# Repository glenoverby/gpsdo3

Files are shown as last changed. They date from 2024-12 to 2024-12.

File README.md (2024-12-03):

# gpsdo3
Improved GPS Disciplined Oscillator

This is a GPS Disciplined Oscillator for synchronizing a 10MHz osillator
with the timing signal from GPS.

This project include a printed circuit board (designed in KiCad) and software
(using Arduino).  It runs on a SparkFun SAMD21 Mini Breakout.

A full description of the project is in the 'doc' directory.

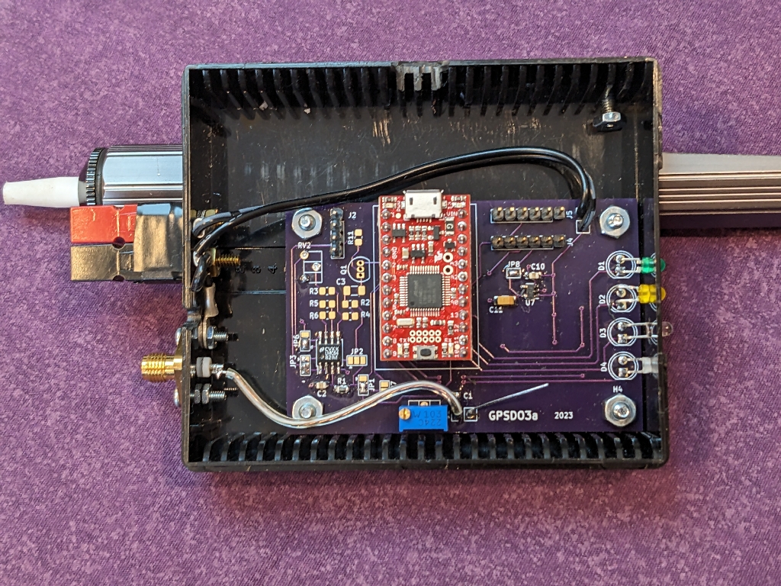
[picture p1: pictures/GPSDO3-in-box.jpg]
Image of board wired up


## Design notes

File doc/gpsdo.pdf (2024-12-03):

# An Improved GPS Disciplined Oscillator

Glen Overby, KC0IYT 11/2024 This is a GPS Disciplined Oscillator for synchronizing a 10MHz signal source with the timing signal from GPS. It uses a Atmel/Microchip SAMD-21 microcontroller to achieve this.

## Background

This is a follow-on to my 2017 GPSDO project with an improved PCB and improved software. The software now locks a 10MHz oscillator such that when driving a synthesized oscillator at 5.7GHZ, the signal will be within 500HZ and locks up in less than 30 seconds from when the GPS gets a 3D lock and produces an accurate 1PPS signal.
My 2017 GPSDO project never worked well for me, primarily because the lock time was too long. I purchased a GPSDO made by a Chinese ham, BG7TBL, and was using it on my 10GHz ham radio station in the summer of 2023. I had a number of comments about the amount of spurious garbage on my RF signal at 10GHz, which resulted in my doing comparisons of driving a 10GHz synthesized oscillator with several different oscillators: the GPSDO, and several good quality ovenised oscillators (OCXOs). The difference was easily apparent: the OCXOs were much better. Even my own GPSDO turned the output from a good OCXO into one that generated spurs. I needed something better.
There are other commercial GPSDOs available, probably for less than I spent on this project, but I heard some bad signals on the radio from people who were using them. I decided to make improvements to my own GPSDO (in retrospect, this may have been due to their power supply).

## Hardware

My Version 1 GPSDO project used a TI MSP432 microcontroller. There were some compromises, like not being able to read the GPS serial stream directly, due to pins being shared between the microcontroller’s peripherals. The development environment, based on Eclipse, ran on Windows and I prefer to use Linux. So for a GPSDO revision, a change in microcontroller was on the table. I had purchased some SparkFun SAMD21 based Arduino boards, which use a 30 MHz ARM chip with a large set of peripherals, for a model rocket project. It’s completely overkill for the task at hand. However, the MegaAVRs weren’t quite up to the task of counting a 10 MHz clock. The SparkFun SAMD-21 Arduio board costs about $20, and I might make 2 or 3 of them, my time is a bigger factor than the cost of the chip.
I prototyped a new GPSDO using an unused GPSDO v1 PCB with good results, so I proceeded

1

with the project.
One of the lessons I learned with the version 1 was to have separate voltage regulators for different parts of the circuit. In particular, the GPS needs to not share a regulator with the microcontroller. My V1 GPSDO had a 1HZ noise pulse that was remedied by moving the GPS module to it’s own regulator.
Another lesson in power domains was turning on/off LEDs affected the PWM output voltage enough to cause a noticeable sawtooth pattern on the output signal at 10GHz. This problem did not repeat during this project, even though the LEDs are driven by the microcontroller. This may be due, in part, to using the microcontroller to sink current (the ground side of LEDs is connected to the chip) instead of source it. The one exception to this is the red/green LED for the GPS lock.
Another discovery I made while working with the prototype - that might explain problems with v1 - was how much better the resulting oscillator’s signal was when driven from the SAMD21’s DAC as compared to a PWM signal with filters. The MSP430 only had a PWM, while the SAMD21 has a real DAC (I assume it’s based on resistors). Even though the SAMD21 had a DAC on it, I started out using a PWM DAC because I believed I needed more than 10 bits of resolution to control the OCXO. That’s only partly correct; the number of bits required depends greatly on what OCXO is being used. The PCB has a footprint for a MCP 4725 12-bit DAC chip, in case I ever need a DAC with more resolution.
The Arduino environment supports using the SAMD-21 USB hardware as a client, making it look like a serial port to the host. This means I only had to use one hardware serial port to listen to the GPS for lock signal (the SAMD-21 has multiple hardware serial ports).
Inputs from the oscillator, GPS, etc. are buffered using a 74HCT125 chip. The HCT technology is safe to use with +5V inputs when the chip is powered by 3.3v.
The serial port connections use a 6-pin header compatible with the headers used on many Arduino boards and many USB to Serial adapters. There is one header to connect to the GPS receiver (with the 1PPS signal taking over the DTR pin). A second header is present to connect a USB-to-Serial adapter to the GPS receiver.
A header is provided for connections to the oscillator. It includes power for the voltage control op-amp and a signal for when the oscillator has reached operating temperature (both of those were inspired by the Isotemp OCXOs).
There are many jumper points on the board:
JP1 selects the CPU DAC or PWM pins. JP7 connects the output pin of the external DAC, if used (KiCad doesn’t have a 3-way jumper). This signal goes to an RC filter then to the first half of op-amp U1.
JP2 selects the input of the second half of op-amp U1. Options are the output of the first half of U1 or the signal selected by JP1/JP7.
JP3 selects which op-amp section goes to the OCXO control.

2

JP5 selects where the op-amp power comes from: either the 3.3v rail or the Oscillator’s control voltage.
JP4, JP5 and JP8 are on the outputs of the voltage regulators. This allows testing the voltage regulator without powering any circuitry, and measuring current draw.
The first half of op-amp U1 is a simple input follower[2] after filter R1/C2. The second half has component footprints (R3, R4, R5, R6, RV2) to make it a summing amplifier[1]. This was intended to provide an offset voltage for use with OCXOs that require a control voltage higher than 3.3v. Alternatively, it can be a non-inverting amplifier[1] with a gain greater than 1 by placing resistors at R5, R6.
The 10MHz clock source is terminated by RV1, a 5K ohm variable resistor. This resistor is used to adjust the voltage level seen by the 74HCT125 input, and is the only tuning the board requires. Adjust the resistor so the 10MHz signal appears on the output of U2, pin 8. I needed an oscilloscope to get this setting right.

## Software

I had many ideas for how to improve the GPS lock software. The software is a PID controller (PID controllers are described in detail in various places on the the internet; I won’t try to go into them here). The major problem I needed to address was the time it takes to lock the oscillator frequency to the GPS timing signal.
My V1 software always averaged multiple 1PPS clocks before operating on them. This was to remove jitter in the GPS signal (or maybe in the receiver chip). The jitter usually exhibited itself as one clock that was long or short, with the next clock compensating.
I decided that the P controller, which is doing only a rough lock to 1PPS, can operate well even with a little bit of jitter from the GPS since the P controller has a small error band. This version does that, and by operating every second, it locks the oscillator much faster than the old version. For the I controller, I continue to average several 1PPS clocks but do so using a moving average. This allows running the I controller every second. I discovered that I needed to use double precision floating point to have enough bits for an average of 10,000,000 samples and including a fraction (single precision, 32 bits, used all the bits for the integer portion of the number). It’s good that I picked a microcontroller that was a lot of overkill! I’ve since revisited this decision and am now tracking the error (how far from 10,000,000 the actual count is) and single precision floating point works well.
The software starts as a P controller then switches to an I controller once P is stable “enough”. It will switch back to the P controller if an adjustment needs to be too large.
I found that after making adjustments in the I controller, I really needed to flush out the accumulated error. If I didn’t, the I controller would swing from too fast to too slow, never (or rarely) stopping in the middle.
Configuring the SAMD21 is quite complicated. I borrowed code from the Arduino forum for

3

configuring a counter with an external clock and a capture-and-hold. The choice in what counter and sample and hold determined what pins the 10MHz signal and the PPS signal were connected. Similarly, the code for initializing the PWM DAC was borrowed from the Arduino wiring_analog library (which I actually call once during configuration so that I didn’t need to duplicate even more code).
Once the board has been assembled an the OCXO connected,
I’ve used this to control several OCXOs:
- CTi OSC5A2B02
- Isotemp 134-10
- FOX 801

## Lessons Learned

There were a few problems encountered along the way:
I configured A0, shared with the DAC output, as a digital output. This caused a problem where the DAC wouldn’t swing all the way to 3.3v due to the digital signal pulling it down. I left the initialization in the code, commented out, along with a warning to my future self not to use it. Whenever the counter for the 10MHz clock wraps at 2**32, it reports 32 extra clocks. I don’t know where it gets them. It’s not good to interject a glitch every 429 seconds, so I check for outliers and throw away bad samples. Just in case something goes awry, there is a counter: if 10 outliers in a row happen, the code kicks back to the P controller (that actually happened when a test clip came off).
While the PI controllers need to operate based on the 1PPS GPS clock, I needed status LEDs to update even when that clock isn’t present (e.g. to update the GPS lock LED to RED!). The loop() function uses the Arduino millis() call to get the time, and updates LEDs about every 2 seconds. The heartbeat update will be noticeably slower when this is happening.
The normal program output, on the USB serial port, only shows status when changes are made to the OCXO control signal. Debugging can be turned on to increase the amount of chatter. All messages from the GPS can be echoed to that serial port as well. Normally only the $GPRMC signal is passed (which can be used to set a computer’s clock).
The second board I built didn’t include the 10K trim pot on the I found that oscillators weren’t behaving themselves. After adding it, things improved significantly. I think the oscillators didn’t like the high impedance input and need the ~5k ohms of termination.
I’m using a resistive power splitter on the oscillator output, but I think I need to add a MMIC on each side of the splitter both for isolation and to bring the power level up. I have several of the CTi oscillators, and the ones without the GPSDO are cleaner than the ones on the GPSDO.
The FOX 801 really needs more than a 10 bit DAC. I used those with my V1 GPSDO which is

4

probably why I started this project thinking that I couldn’t use the 10-bit DAC.
I’ve found that having a GPS with a separate antenna is a lot more useful than having the antenna integrated with the GPSDO box. With an external antenna, I can mount the GPSDO wherever it works best, without requiring that the whole thing having a sky view.
While I’ve put the GPSDO in a plastic box, I’ve been keeping the oscillator in a separate metal box.

## Future

Some things that could use improving for future versions:
I have a simple RC filter on the control output, along with op-amps to buffer it. I should try using a salen-key low pass filter with one of the op-amps.
I designed the op-amp circuit to allow adding a constant voltage (Isotemp OCXOs use about 8v for the voltage control), but when I tried using that OCXO I actually used a 2x amplification. Provide some tap points for DC power and ground on the PCB – probably a 2nd 2-pin header right next to the first one. This would have made it easier to build a version that is integrated with the OCXO.
The header for the OCXO should be expanded to include a pin for power TO the OCXO, and a jumper to connect it to +12v power coming onto the board.
Label the GPS connectors better. There are two 6-pin headers (compatible with readily available USB to serial boards used on Arduinos): one connects to the GPS, another to a USB-to-Serial adapter in case I ever wish to program the GPS. It’s easy to forget which is which, and which way to connect the cable.
There may be better ways to buffer the input 10MHz signal. A similar project by VE2ZAZ published in QEX[3] used an LTC1485 differential bus transceiver.

## References

[1] National Semiconductor AN-31 “Op Amp Circuit Collection”, February 1978. Non-Inverting Summing Amplifier
[2] National Semiconductor LMC6482 “CMOS Dual Rail-To-Rail Input and Output Operational Amplifier” data sheet, November 1977, Figure 10.
[3] “A Simplified GPS-Derived Frequency Standard”, Bertrand Zauhar VE2ZAZ QEX Sep 2006 pp 14 https://webpubs.arrl.org/pubs_archive/113782

5

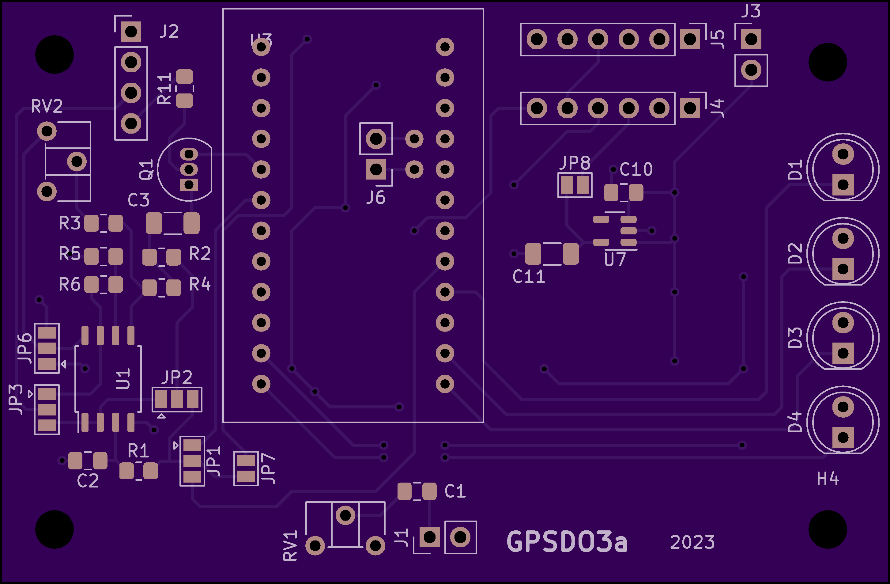
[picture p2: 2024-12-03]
pictures/GPSDO3-top.png

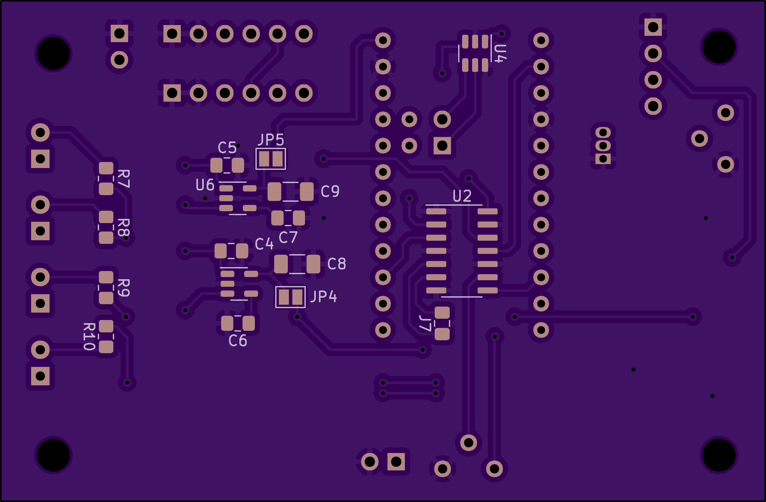
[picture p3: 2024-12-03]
pictures/GPSDO3-bottom.png

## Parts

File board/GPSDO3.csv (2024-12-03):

Source: | /home/glen/kicad/GPSDO3/GPSDO3.kicad_sch
Date: | Tue Nov 14 01:06:51 2023
Tool: | Eeschema 7.0.9-7.0.9~ubuntu22.04.1
Generator: | /usr/share/kicad/plugins/bom_csv_grouped_by_value.py
Component Count: | 55
Collated Components:
Item | Qty | Reference(s) | Value | LibPart | Footprint | Datasheet | DNP
1 | 1 | C1 | C | Device:C | Capacitor_SMD:C_0805_2012Metric_Pad1.18x1.45mm_HandSolder | ~
2 | 4 | C2, C4, C5, C10 | 1uF | Device:C | Capacitor_SMD:C_0805_2012Metric_Pad1.18x1.45mm_HandSolder | ~
3 | 1 | C3 | 1uF | Device:C | Capacitor_SMD:C_1206_3216Metric_Pad1.33x1.80mm_HandSolder | ~
4 | 2 | C6, C7 | 470pF | Device:C | Capacitor_SMD:C_0805_2012Metric_Pad1.18x1.45mm_HandSolder | ~
5 | 3 | C8, C9, C11 | 2.2uF | Device:C_Polarized_US | Capacitor_SMD:C_1206_3216Metric_Pad1.33x1.80mm_HandSolder | ~
6 | 4 | D1, D2, D3, D4 | LED | Device:LED | LED_THT:LED_D5.0mm | ~
7 | 4 | H1, H2, H3, H4 | MountingHole | Mechanical:MountingHole | MountingHole:MountingHole_3.2mm_M3 | ~
8 | 1 | J1 | Conn_Coaxial | Connector:Conn_Coaxial | Connector_PinHeader_2.54mm:PinHeader_1x02_P2.54mm_Vertical | ~
9 | 1 | J2 | To OSC | Connector:Conn_01x04_Male | Connector_PinHeader_2.54mm:PinHeader_1x04_P2.54mm_Vertical | ~
10 | 1 | J3 | Power | Connector:Conn_01x02_Male | Connector_PinHeader_2.54mm:PinHeader_1x02_P2.54mm_Vertical | ~
11 | 1 | J4 | To GPS | Connector:Conn_01x06_Male | Connector_PinHeader_2.54mm:PinHeader_1x06_P2.54mm_Vertical | ~
12 | 1 | J5 | To Computer | Connector:Conn_01x06_Male | Connector_PinHeader_2.54mm:PinHeader_1x06_P2.54mm_Vertical | ~
13 | 1 | J6 | Conn_01x02_Male | Connector:Conn_01x02_Male | Connector_PinHeader_2.54mm:PinHeader_1x02_P2.54mm_Vertical | ~
14 | 1 | J7 | Conn_01x02_Male | Connector:Conn_01x02_Male | Capacitor_SMD:C_0805_2012Metric_Pad1.18x1.45mm_HandSolder | ~
15 | 1 | JP1 | CPU PWM - DAC | Jumper:SolderJumper_3_Bridged12 | Jumper:SolderJumper-3_P1.3mm_Open_Pad1.0x1.5mm | ~
16 | 1 | JP2 | Gate2 Input | Jumper:SolderJumper_3_Bridged12 | Jumper:SolderJumper-3_P1.3mm_Open_Pad1.0x1.5mm | ~
17 | 1 | JP3 | OSC Vcontrol | Jumper:SolderJumper_3_Bridged12 | Jumper:SolderJumper-3_P1.3mm_Open_Pad1.0x1.5mm | ~
18 | 1 | JP4 | 5V #1 Jumper | Jumper:SolderJumper_2_Open | Jumper:SolderJumper-2_P1.3mm_Open_Pad1.0x1.5mm | ~
19 | 1 | JP5 | 5V #2 Jumper | Jumper:SolderJumper_2_Open | Jumper:SolderJumper-2_P1.3mm_Open_Pad1.0x1.5mm | ~
20 | 1 | JP6 | ~ | Jumper:SolderJumper_3_Bridged12 | Jumper:SolderJumper-3_P1.3mm_Open_Pad1.0x1.5mm | ~
21 | 1 | JP7 | SolderJumper_2_Open | Jumper:SolderJumper_2_Open | Jumper:SolderJumper-2_P1.3mm_Open_Pad1.0x1.5mm | ~
22 | 1 | JP8 | 3.3V Jumper | Jumper:SolderJumper_2_Open | Jumper:SolderJumper-2_P1.3mm_Open_Pad1.0x1.5mm | ~
23 | 1 | Q1 | 2N3904 | Transistor_BJT:2N3904 | Package_TO_SOT_THT:TO-92_Inline | https://www.onsemi.com/pub/Collateral/2N3903-D.PDF
24 | 4 | R1, R2, R3, R4 | 100K | Device:R_US | Resistor_SMD:R_0805_2012Metric_Pad1.20x1.40mm_HandSolder | ~
25 | 2 | R5, R6 | 10K | Device:R_US | Resistor_SMD:R_0805_2012Metric_Pad1.20x1.40mm_HandSolder | ~
26 | 5 | R7, R8, R9, R10, R11 | R_US | Device:R_US | Resistor_SMD:R_0805_2012Metric_Pad1.20x1.40mm_HandSolder | ~
27 | 1 | RV1 | R_Potentiometer_US | Device:R_Potentiometer_US | Potentiometer_THT:Potentiometer_ACP_CA6-H2,5_Horizontal | ~
28 | 1 | RV2 | 10K | Device:R_Potentiometer_US | Potentiometer_THT:Potentiometer_ACP_CA6-H2,5_Horizontal | ~
29 | 1 | U1 | LMC6482 | Amplifier_Operational:LMC6482 | Package_SO:SOIC-8_5.23x5.23mm_P1.27mm | http://www.ti.com/lit/ds/symlink/lmc6482.pdf
30 | 1 | U2 | 74LVC125 | 74xx:74LVC125 | Package_SO:SOIC-14_3.9x8.7mm_P1.27mm | http://www.ti.com/lit/gpn/sn74LVC125
31 | 1 | U3 | SFE_SAMD21_Mini | Glen_Arduino:SFE_SAMD21_Mini | Glen_Arduino:SFE SAMD21 Mini
32 | 1 | U4 | MCP4725xxx-xCH | Analog_DAC:MCP4725xxx-xCH | Package_TO_SOT_SMD:SOT-23-6 | http://ww1.microchip.com/downloads/en/DeviceDoc/22039d.pdf
33 | 1 | U5 | MIC5205-3.3YM5 | Regulator_Linear:MIC5205-3.3YM5 | Package_TO_SOT_SMD:SOT-23-5 | http://ww1.microchip.com/downloads/en/DeviceDoc/20005785A.pdf
34 | 2 | U6, U7 | MIC5205-5.0YM5 | Regulator_Linear:MIC5205-5.0YM5 | Package_TO_SOT_SMD:SOT-23-5 | http://ww1.microchip.com/downloads/en/DeviceDoc/20005785A.pdf

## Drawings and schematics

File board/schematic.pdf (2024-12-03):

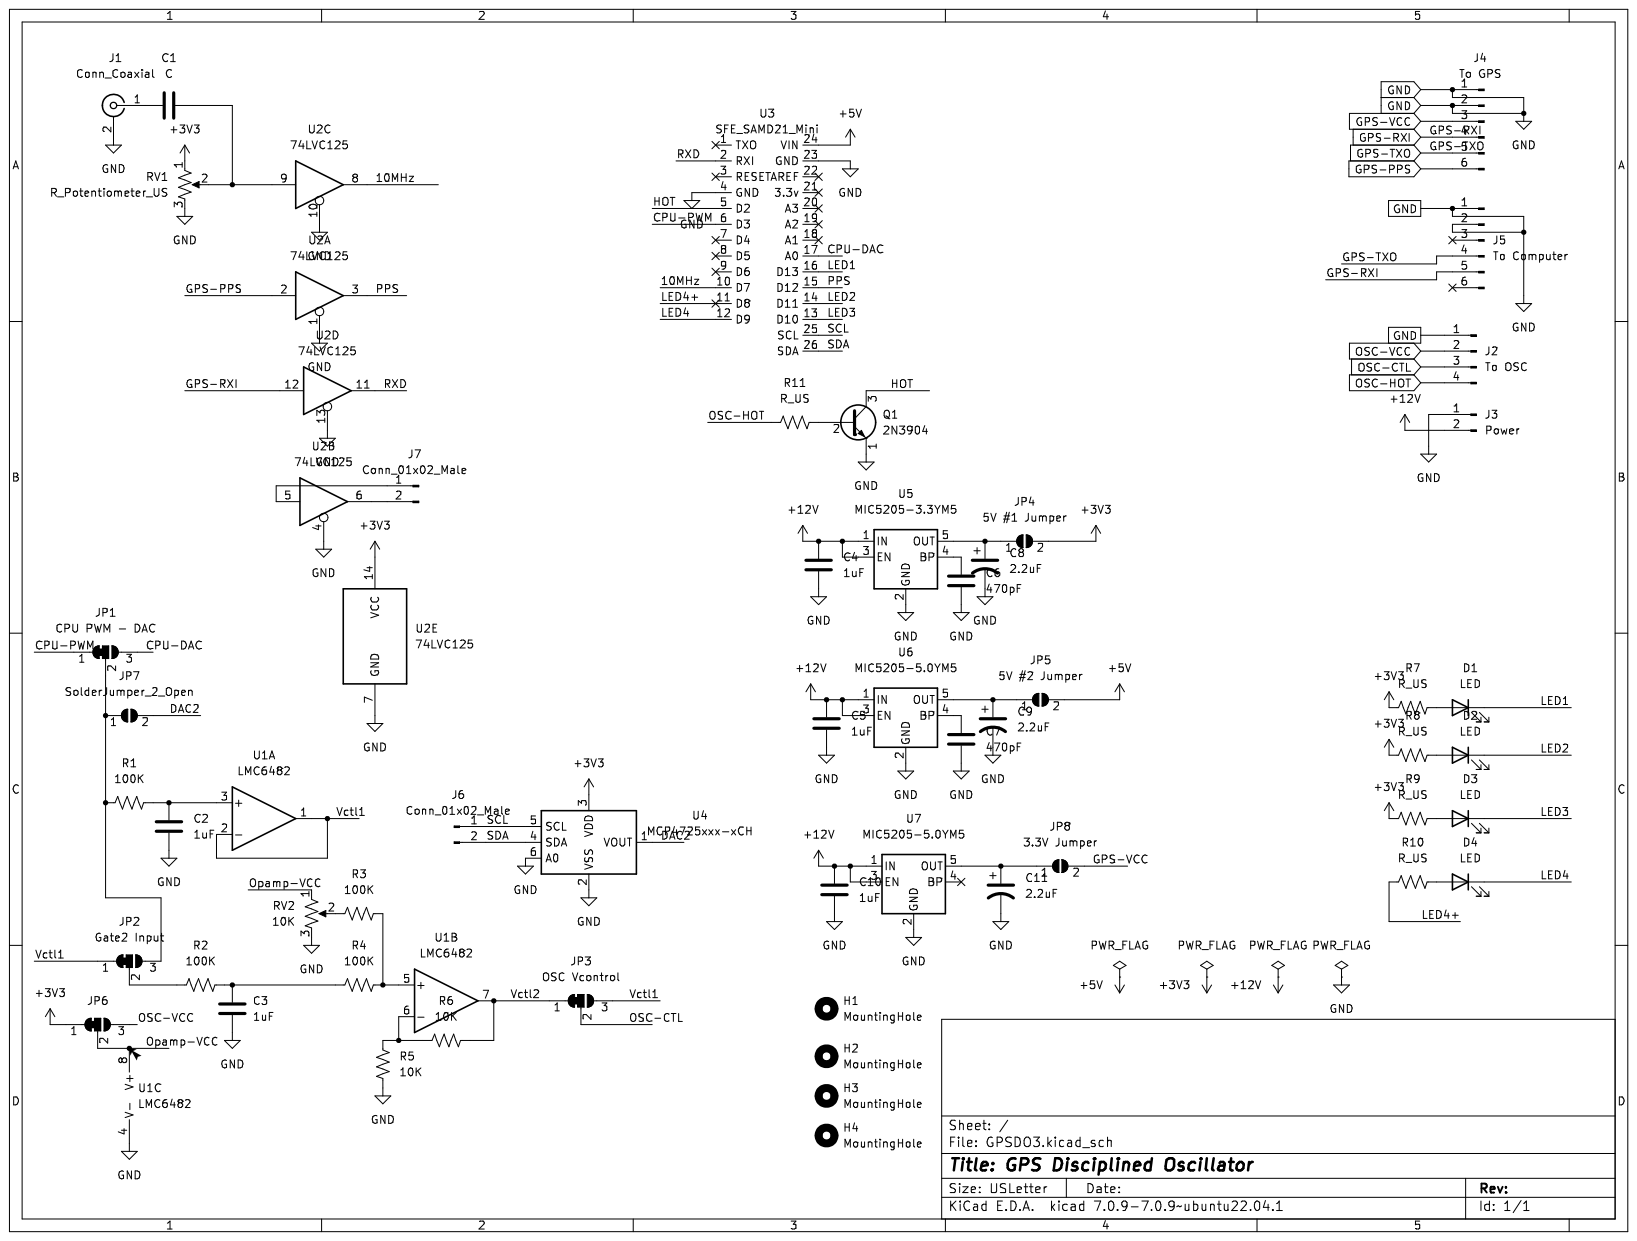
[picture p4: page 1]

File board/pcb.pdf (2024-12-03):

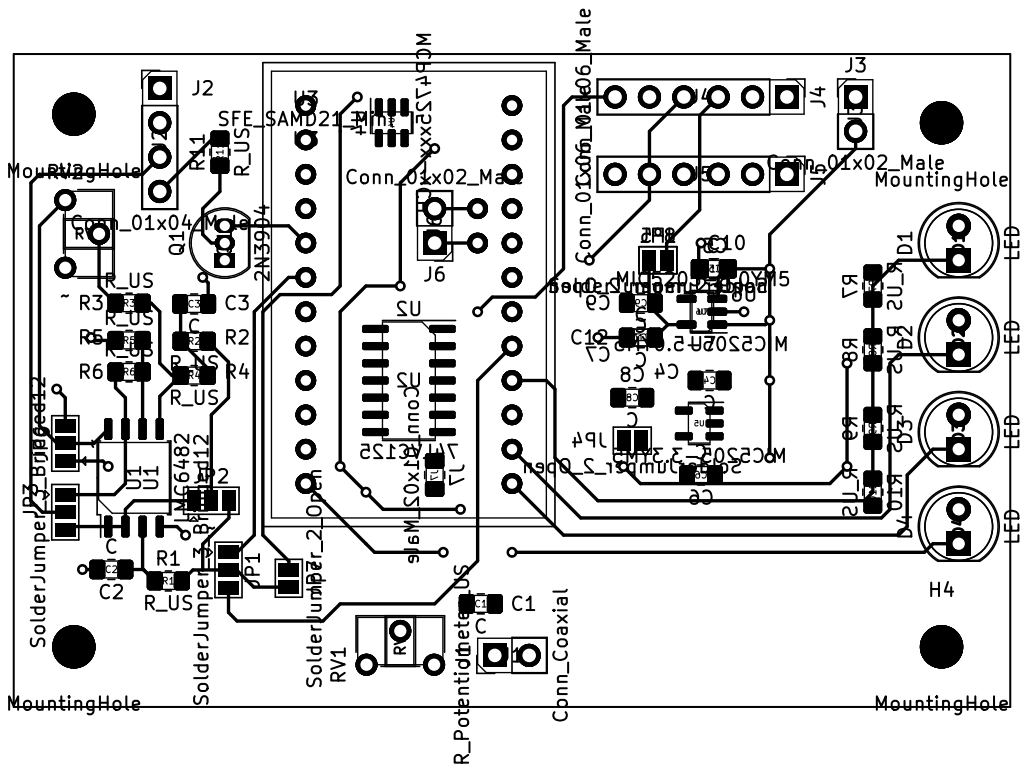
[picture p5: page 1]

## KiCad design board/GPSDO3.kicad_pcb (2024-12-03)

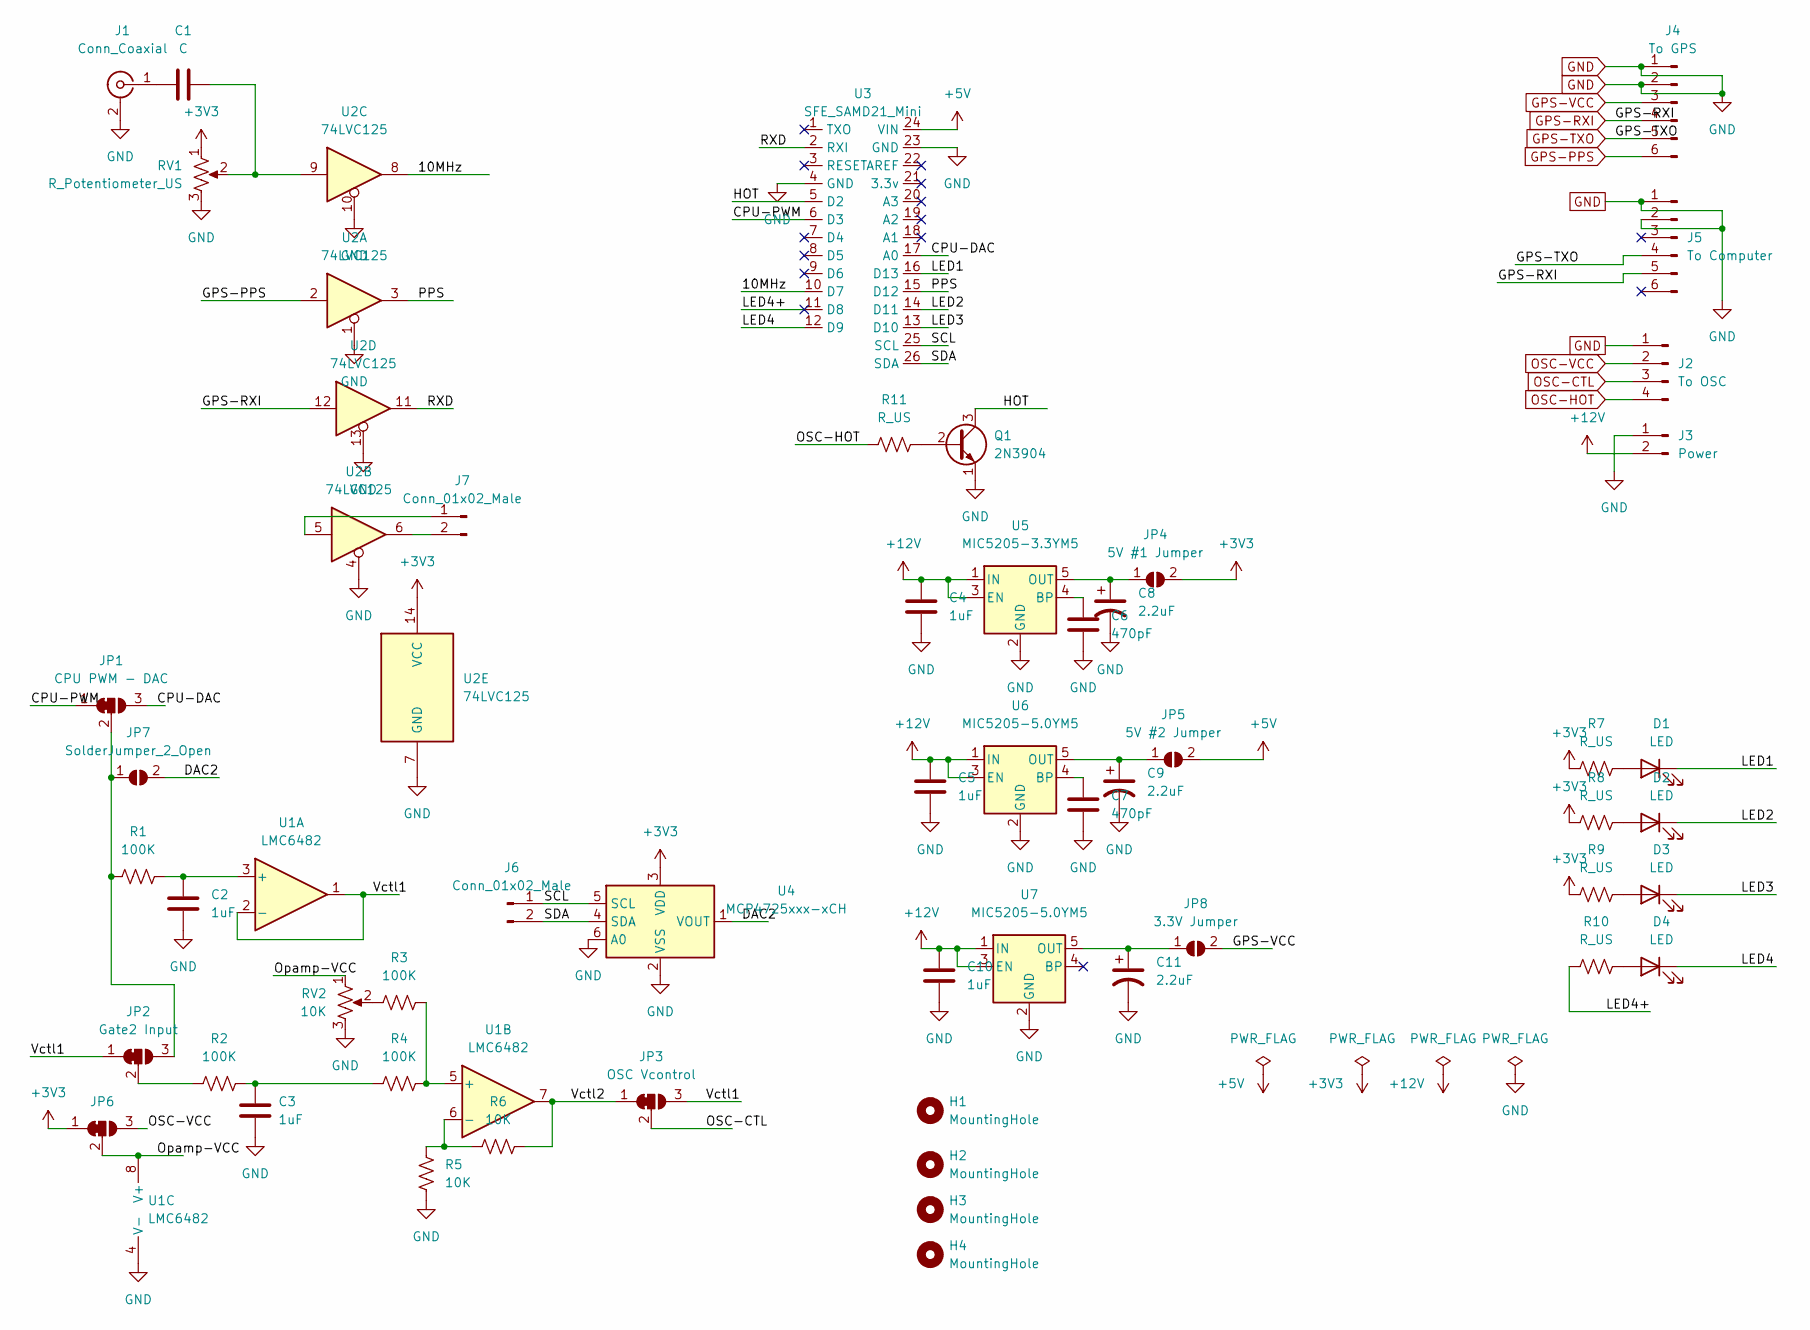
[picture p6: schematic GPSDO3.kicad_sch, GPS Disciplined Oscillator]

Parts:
C1: C; C_0805_2012Metric_Pad1.18x1.45mm_HandSolder
C2, C4, C5, C10: 1uF; C_0805_2012Metric_Pad1.18x1.45mm_HandSolder
C3: 1uF; C_1206_3216Metric_Pad1.33x1.80mm_HandSolder
C6, C7: 470pF; C_0805_2012Metric_Pad1.18x1.45mm_HandSolder
C8, C9, C11: 2.2uF; C_1206_3216Metric_Pad1.33x1.80mm_HandSolder
D1, D2, D3, D4: LED; LED_D5.0mm
H1, H2, H3, H4: MountingHole; MountingHole_3.2mm_M3
J1: Conn_Coaxial; PinHeader_1x02_P2.54mm_Vertical
J2: To OSC; PinHeader_1x04_P2.54mm_Vertical
J3: Power; PinHeader_1x02_P2.54mm_Vertical
J4: To GPS; PinHeader_1x06_P2.54mm_Vertical
J5: To Computer; PinHeader_1x06_P2.54mm_Vertical
J6: Conn_01x02_Male; PinHeader_1x02_P2.54mm_Vertical
J7: Conn_01x02_Male; C_0805_2012Metric_Pad1.18x1.45mm_HandSolder
JP1: CPU PWM - DAC; SolderJumper-3_P1.3mm_Open_Pad1.0x1.5mm
JP2: Gate2 Input; SolderJumper-3_P1.3mm_Open_Pad1.0x1.5mm
JP3: OSC Vcontrol; SolderJumper-3_P1.3mm_Open_Pad1.0x1.5mm
JP4: 5V #1 Jumper; SolderJumper-2_P1.3mm_Open_Pad1.0x1.5mm
JP5: 5V #2 Jumper; SolderJumper-2_P1.3mm_Open_Pad1.0x1.5mm
JP6: SolderJumper-3_P1.3mm_Open_Pad1.0x1.5mm
JP7: SolderJumper_2_Open; SolderJumper-2_P1.3mm_Open_Pad1.0x1.5mm
JP8: 3.3V Jumper; SolderJumper-2_P1.3mm_Open_Pad1.0x1.5mm
Q1: 2N3904; TO-92_Inline
R1, R2, R3, R4: 100K; R_0805_2012Metric_Pad1.20x1.40mm_HandSolder
R5, R6: 10K; R_0805_2012Metric_Pad1.20x1.40mm_HandSolder
R7, R8, R9, R10, R11: R_US; R_0805_2012Metric_Pad1.20x1.40mm_HandSolder
RV1: R_Potentiometer_US; Potentiometer_ACP_CA6-H2,5_Horizontal
RV2: 10K; Potentiometer_ACP_CA6-H2,5_Horizontal
U1: LMC6482; SOIC-8_5.23x5.23mm_P1.27mm
U2: 74LVC125; SOIC-14_3.9x8.7mm_P1.27mm
U3: SFE_SAMD21_Mini; SFE SAMD21 Mini
U4: MCP4725xxx-xCH; SOT-23-6
U5: MIC5205-3.3YM5; SOT-23-5
U6, U7: MIC5205-5.0YM5; SOT-23-5

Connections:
+3V3: JP4.2 (B), JP6.1 (A), R7.2, R8.2, R9.2, RV1.1, U2.14 (VCC), U4.3 (VDD)
+5V: JP5.2 (B), U3.24 (VIN)
+12V: C4.1, C5.1, C10.1, J3.2, U5.1 (IN), U5.3 (EN), U6.1 (IN), U6.3 (EN), U7.1 (IN), U7.3 (EN)
/10MHz: U2.8, U3.10 (D7)
/CPU-DAC: JP1.3 (B), U3.17 (A0)
/CPU-PWM: JP1.1 (A), U3.6 (D3)
/DAC2: JP7.2 (B), U4.1 (VOUT)
/HOT: Q1.3 (C), U3.5 (D2)
/LED1: D1.1 (K), U3.16 (D13)
/LED2: D2.1 (K), U3.14 (D11)
/LED3: D3.1 (K), U3.13 (D10)
/LED4: D4.1 (K), U3.12 (D9)
/LED4+: R10.2, U3.11 (D8)
/Opamp-VCC: JP6.2 (C), RV2.1, U1.8 (V+)
/PPS: U2.3, U3.15 (D12)
/RXD: U2.11, U3.2 (RXI)
/SCL: J6.1, U3.25 (SCL), U4.5 (SCL)
/SDA: J6.2, U3.26 (SDA), U4.4 (SDA)
/Vctl1: JP2.1 (A), JP3.3 (B), U1.1, U1.2 (-)
/Vctl2: JP3.1 (A), R6.2, U1.7
GND: C2.2, C3.2, C4.2, C5.2, C6.2, C7.2, C8.2, C9.2, C10.2, C11.2, J1.2 (Ext), J2.1, J3.1, J4.1, J4.2, J5.1, J5.2, Q1.1 (E), R5.2, RV1.3, RV2.3, U1.4 (V-), U2.1, U2.4, U2.7 (GND), U2.10, U2.13, U3.4 (GND), U3.23 (GND), U4.2 (VSS), U4.6 (A0), U5.2 (GND), U6.2 (GND), U7.2 (GND)
GPS-PPS: J4.6, U2.2
GPS-RXI: J4.4, J5.5, U2.12
GPS-TXO: J4.5, J5.4
GPS-VCC: J4.3, JP8.2 (B)
unnamed: C1.1, RV1.2, U2.9
unnamed: C3.1, R2.1, R4.2
unnamed: D1.2 (A), R7.1
unnamed: D2.2 (A), R8.1
unnamed: D3.2 (A), R9.1
unnamed: D4.2 (A), R10.1
unnamed: C1.2, J1.1 (In)
unnamed: J7.1, U2.5
unnamed: J7.2, U2.6
unnamed: JP1.2 (C), JP2.3 (B), JP7.1 (A), R1.2
unnamed: JP2.2 (C), R2.2
unnamed: C8.1, JP4.1 (A), U5.5 (OUT)
unnamed: C9.1, JP5.1 (A), U6.5 (OUT)
unnamed: C11.1, JP8.1 (A), U7.5 (OUT)
unnamed: Q1.2 (B), R11.1
unnamed: R3.2, RV2.2
unnamed: C2.1, R1.1, U1.3 (+)
unnamed: R3.1, R4.1, U1.5 (+)
unnamed: R5.1, R6.1, U1.6 (-)
unnamed: C6.1, U5.4 (BP)
unnamed: C7.1, U6.4 (BP)
OSC-CTL: J2.3, JP3.2 (C)
OSC-HOT: J2.4, R11.2
OSC-VCC: J2.2, JP6.3 (B)

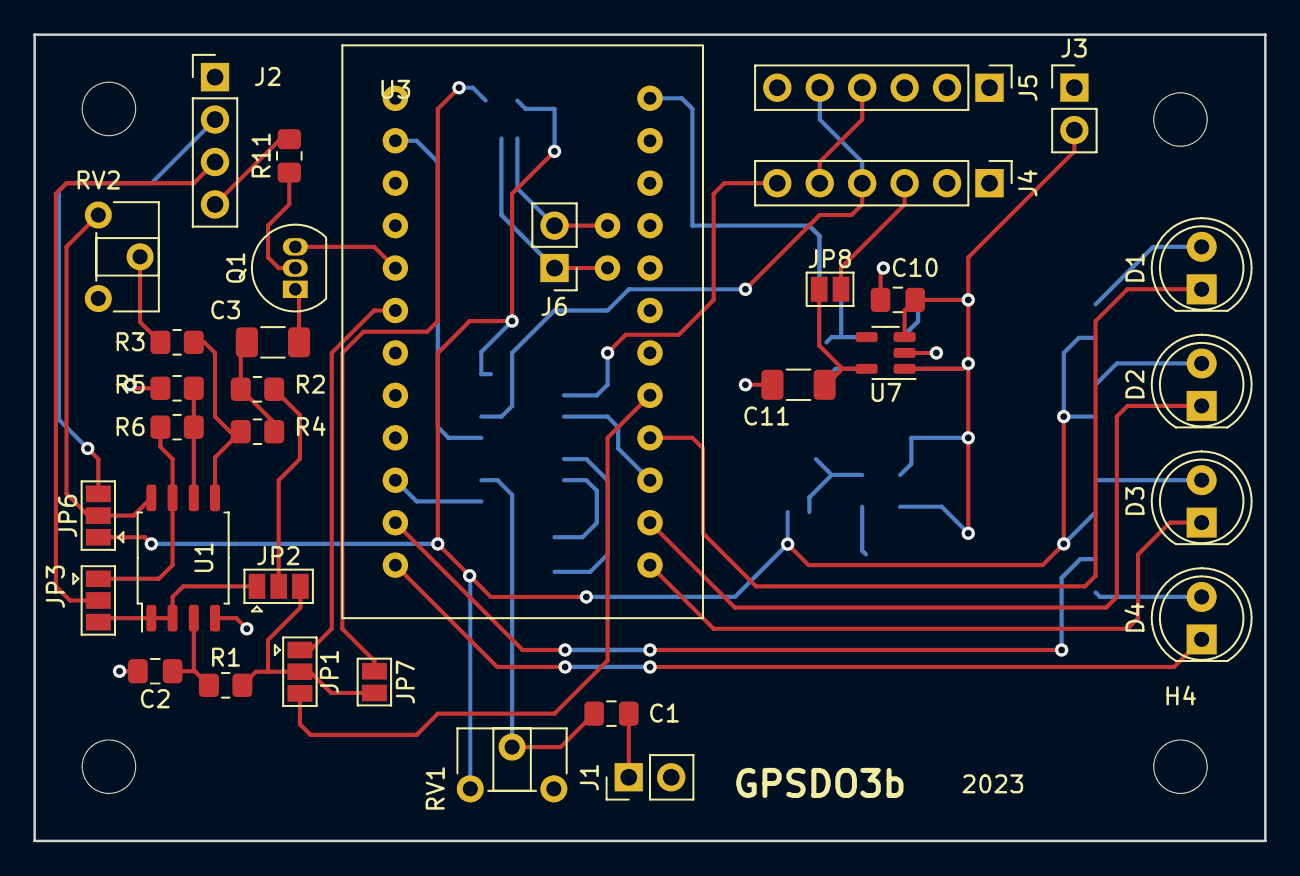
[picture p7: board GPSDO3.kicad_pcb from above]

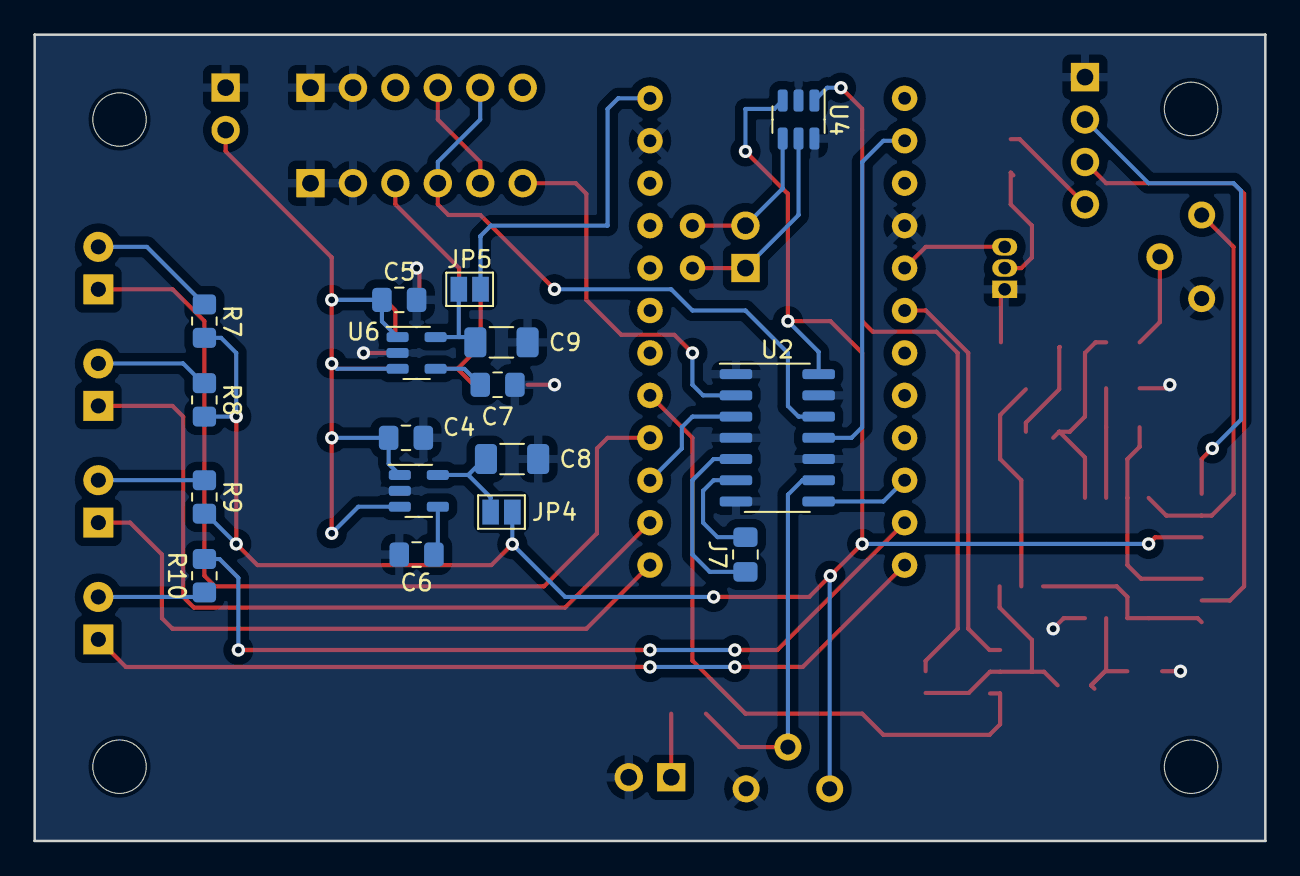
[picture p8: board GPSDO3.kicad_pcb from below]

Board: 2 copper layers, 73.7 x 48.3 mm, 55 parts (17 on the bottom side), 49 nets.

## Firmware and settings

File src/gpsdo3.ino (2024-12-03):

/*
 * Control Systemm for a GPS Disciplined Oscillator
 *
 * Copyright 2023-2024 Glen Overby
 * 
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
 */

// Arduino Pin  Processor Port  Function
// D13          PA17            Blue LED
// D12          PA19            1PPS from GPS
// D7           PA21            10MHz from oscillator
// D3           PA09            PWM output for VControl
//
// D2           PA14            Status LED - on when stable
// D5           PA15            Power LED - on when thinking
//
// D7 is difficult to move because TC4's input is on that pin
//
// LEDs:
//  D1  green     Lock
//  D2  red       Ready
//  D3  orange    Heartbeat
//  D4  red/green GPS status: red no lock, green lock, off no data


// Oscillator Configuration
// P_ADJUST  P controller adjustment factor for PWM DAC (not used)
// PD_ADJUST P controller adjustment factor for DAC
// If_ADJUST I controller adjustment factor
// PD_INIT   Initialization value for DAC
//            These values came from running the GPSDO during development
// USE_HOT  Use the OSC HOT input

#define CTI

#ifdef CTI  // CTi OS5SC25  square wave output oscillator
#define P_ADJUST  266
#define PD_ADJUST 10
#define If_ADJUST 16 / 100
#define PD_INIT -37	// SN#2
// #define ON_STABLE	// SN#1 has a green LED; SN#2 has a red LED
#endif
#ifdef OCXO13410  // Isotemp OCXO134-10
#define P_ADJUST  266
#define PD_ADJUST 25
#define If_ADJUST 24
#define PD_INIT 0
#define USE_HOT
#endif
#ifdef IQD2202   // IQD IQXT-220-2
#define P_ADJUST  266
#define PD_ADJUST 25
#define If_ADJUST 24
#define PD_INIT 0
#endif
#ifdef FOX801   // FOX 801
#define P_ADJUST  2
#define PD_ADJUST 3
#define If_ADJUST 1
#define PD_INIT  19      // initial value for P
#endif
#ifdef CW_T604   // Connor Williams (never got it fully working)
#define P_ADJUST  2
#define PD_ADJUST 1
#define If_ADJUST 1
#define PD_INIT  0      // initial value for P
#endif

#define HEARTBEAT_LED 10   // changes every second to make me happy.
                          // Shows that 1PPS is coming from GPS
#define GPS_LED_A   8     // Red/Green LED. Off=no data, R=no lock, G=2d/3d lock
#define GPS_LED_B   9
#define LOCK_LED   13   // oscillator is locked. Also blue LED
#define READY_LED  11   // general ready.
                        // Oscillator HOT signal would contribute to this.

#define HOT_PIN   2     // Oscillator HOT input (use pull-up)


uint32_t last_count, current_count;
volatile int flag = 0;
uint dacv = 0; // Hardware DAC (10 bits)
int settle=3, Isettle=0;  // Settle timer for startup, etc.
int Pd=0, Id=0;   // I for hardware DAC
double Ia = 0;    // I controller average
float Iea = 0;    // I controller error average
int stable = 0;
int outliers = 0; // Counter for ignoring outliers
int locked = 0;   // Flag for identifying when "locked".
                  // Lock is when no controller is making changes.
int debug = 0;
int Ienable = 1;
int ADJUST = 0;

// These would be locals, but the debug print needs access to them
float Ierror;
int32_t padjust=0, iadjust=0, dadjust=0;

int gpslock = 0;  // non-zero when GPS Lock (from $GPGSA)
int gpsdata = 0;  // last time GPS serial data was seen (counter)
int gpsdebug = 0; // Report data from GPS receiver
int gprmc = 0;    // set true to report $GPRMC. Can be used to set computer's time.

int hb = 0;       // Heartbeat LED flag

ulong nexthb;     // Time of next "software" heartbeat -- using millis()
int pps = 0;      // 1 pulse-per-second from GPS detected

// Wait for synchronization of registers between the clock domains
static __inline__ void syncTCC(Tcc* TCCx) __attribute__((always_inline, unused));
static void syncTCC(Tcc* TCCx) {
  while (TCCx->SYNCBUSY.reg & TCC_SYNCBUSY_MASK);
}


void setup()
{
    // change here to use main clock or input pin
    bool use_clk_pin = true; //false ;

    SerialUSB.begin(115200);
    SerialUSB.println("Hello World");

    Serial1.begin(9600);
    //Serial1.begin(4800);
    Serial.setTimeout(10);

    pinMode(HEARTBEAT_LED, OUTPUT);
    pinMode(LOCK_LED, OUTPUT);
    pinMode(READY_LED, OUTPUT);
    pinMode(GPS_LED_A, OUTPUT);
    pinMode(GPS_LED_B, OUTPUT);
    digitalWrite(HEARTBEAT_LED, LOW); // Turn on all LEDs
    digitalWrite(LOCK_LED, LOW);
    digitalWrite(READY_LED, LOW);
    digitalWrite(GPS_LED_A, LOW);   // Red
    digitalWrite(GPS_LED_B, HIGH);
    pinMode(HOT_PIN, INPUT_PULLUP);

    nexthb = millis() + 2000;

    // Configure hardware DAC
    analogWriteResolution(10); // Set analog out resolution to max, 10-bits
    analogReadResolution(12); // Set analog input resolution to max, 12-bits
    // pinMode(A0, OUTPUT);  BAD - causes DAC to not go over 2.2v
    analogWrite(A0, 0);

    // Configuration Stolen from the internet at 
    // https://forum.arduino.cc/t/running-tc-with-an-external-clock-and-externally-triggered-capture-zero-m0/495066
    //
    // setup main clocks first
    REG_PM_APBAMASK |= PM_APBAMASK_GCLK ;
    REG_PM_APBBMASK |= PM_APBBMASK_PORT ;
    REG_PM_APBCMASK |= PM_APBCMASK_EVSYS | PM_APBCMASK_TC4 | PM_APBCMASK_TC5 ;

    //
    // Configure 32-bit counter TC4/TC5 with it's clock input from PA21(D7)
    // and capture trigger from PA19(D12). Get an interrupt on capture.
    //

    // send generic GCLK0 to the EIC peripheral. This allows using the
    // generic clock for things.
    REG_GCLK_CLKCTRL = GCLK_CLKCTRL_CLKEN | GCLK_CLKCTRL_GEN_GCLK0 | GCLK_CLKCTRL_ID_EIC ;
    while(GCLK->STATUS.bit.SYNCBUSY) ;
    // and to EVSYS peripheral
    REG_GCLK_CLKCTRL = GCLK_CLKCTRL_CLKEN | GCLK_CLKCTRL_GEN_GCLK0 | GCLK_CLKCTRL_ID_EVSYS_0 ;
    while(GCLK->STATUS.bit.SYNCBUSY) ;

    // Send pin PA19 (D12) to EIC (line 1). This is the 1PPS signal from GPS
    //PORT->Group[PORTA].PMUX[17 >> 1].reg |= PORT_PMUX_PMUXO_A ;
    //PORT->Group[PORTA].PINCFG[17].reg |= PORT_PINCFG_PMUXEN ;

    // Enable the port multiplexer on digital pin D12 (port pin PA19)
    PORT->Group[g_APinDescription[12].ulPort].PINCFG[g_APinDescription[12].ulPin].bit.PMUXEN = 1;
    // Feed GCLK5 to TC4/TC5
    // Set up the pin as an EIC (interrupt) peripheral on D12
    PORT->Group[g_APinDescription[12].ulPort].PMUX[g_APinDescription[12].ulPin >> 1].reg |= PORT_PMUX_PMUXO_A;

    // enable ext3 interrupt on rising edge to event system
    REG_EIC_EVCTRL |= EIC_EVCTRL_EXTINTEO3;
    REG_EIC_CONFIG0 |= EIC_CONFIG_SENSE3_RISE;
    // Disable interrupts on interupt 3. We want it as a trigger, not an int
    EIC->INTENCLR.reg = EIC_INTENCLR_EXTINT3; 
    REG_EIC_CTRL |= EIC_CTRL_ENABLE;
    while (EIC->STATUS.bit.SYNCBUSY);

    // direct ext3 event to TC4
    REG_EVSYS_USER = EVSYS_USER_CHANNEL(1) | EVSYS_USER_USER(EVSYS_ID_USER_TC4_EVU) ;
    REG_EVSYS_CHANNEL = EVSYS_CHANNEL_EDGSEL_RISING_EDGE | EVSYS_CHANNEL_PATH_RESYNCHRONIZED 
                        | EVSYS_CHANNEL_EVGEN(EVSYS_ID_GEN_EIC_EXTINT_3) | EVSYS_CHANNEL_CHANNEL(0) ;

    // Source GCLK from PA21 (D7) using gclkio 5
    PORT->Group[PORTA].PMUX[21 / 2].reg = PORT_PMUX_PMUXO_H ;
    PORT->Group[PORTA].PINCFG[21].reg = PORT_PINCFG_PMUXEN ;

    REG_GCLK_GENDIV = GCLK_GENDIV_ID(5) ; // GCLK5: no div

    // Debugging allows use of the main clock instead of the input clock
    if(use_clk_pin) {
        // Feed from GCLK_IO to GCLK5
        REG_GCLK_GENCTRL = GCLK_GENCTRL_GENEN | GCLK_GENCTRL_RUNSTDBY | GCLK_GENCTRL_SRC_GCLKIN  | GCLK_GENCTRL_ID(5) ;
        while (GCLK->STATUS.bit.SYNCBUSY);
    } else {
        // clock from main clock
        REG_GCLK_GENCTRL = GCLK_GENCTRL_GENEN | GCLK_GENCTRL_RUNSTDBY | GCLK_GENCTRL_SRC_DFLL48M | GCLK_GENCTRL_ID(5) ;
        while (GCLK->STATUS.bit.SYNCBUSY);
    }

    // Feed GCLK5 to TC4/TC5
    REG_GCLK_CLKCTRL = GCLK_CLKCTRL_CLKEN | GCLK_CLKCTRL_GEN_GCLK5 | GCLK_CLKCTRL_ID_TC4_TC5 ;
    while (GCLK->STATUS.bit.SYNCBUSY);
    
    // Enable TC4 event input
    REG_TC4_EVCTRL |= TC_EVCTRL_TCEI ;

    // set capture on TC4/5 channel 0
    REG_TC4_READREQ = TC_READREQ_RREQ | TC_READREQ_ADDR(0x06) ;
    while (TC4->COUNT32.STATUS.bit.SYNCBUSY) ;
    REG_TC4_CTRLC |= TC_CTRLC_CPTEN0 ;
    while (TC4->COUNT32.STATUS.bit.SYNCBUSY) ;

    // enable timer TC4 interrupt for Capture events
    NVIC_SetPriority(TC4_IRQn, 0) ;
    NVIC_EnableIRQ(TC4_IRQn) ;
    REG_TC4_INTENSET = TC_INTENSET_MC0 ;

    // no prescaler, 32 bit mode (uses TC4 & TC5)
    REG_TC4_CTRLA |= TC_CTRLA_PRESCALER_DIV1 | TC_CTRLA_MODE_COUNT32 | TC_CTRLA_ENABLE ;
    while (TC4->COUNT16.STATUS.bit.SYNCBUSY) ;

    // Read counter register continuously
    REG_TC4_READREQ = TC_READREQ_RCONT | TC_READREQ_ADDR(0x10); // COUNT offset 0x10

    Pd = PD_INIT;
    adjust(1, 0, 0, 0);
    SerialUSB.println("config done");
}

void TC4_Handler()
{
    uint32_t count ;
  
    // Check for match counter 0 (MC0) interrupt
    // read automatically clears flag      
    if (TC4->COUNT16.INTFLAG.bit.MC0) {
        REG_TC4_READREQ = TC_READREQ_RREQ | TC_READREQ_ADDR(0x18);
        while (TC4->COUNT32.STATUS.bit.SYNCBUSY);
        count = REG_TC4_COUNT32_CC0;

        current_count = count;
        flag = 1;
    }
}


void serial_status()
{
  if (SerialUSB.available() > 0) {
    // read the incoming byte:
    int incomingByte;
    incomingByte = SerialUSB.read();
    if (incomingByte == 'd') {  // Control general debug
      debug++;
    } else if (incomingByte == 'D') {
      debug = 0;
    } else if (incomingByte == 's') { // Report status
      volatile uint32_t count = REG_TC4_COUNT32_COUNT ;
      SerialUSB.print("Count ");
      SerialUSB.print(current_count);
      SerialUSB.print(" ");
      SerialUSB.print(count);
      SerialUSB.print(" settle ");
      SerialUSB.print(settle);
      SerialUSB.print(" Ia ");
      SerialUSB.print(Ia);
      SerialUSB.print(" Iea ");
      SerialUSB.print(Iea);
      SerialUSB.print(" dacv ");
      SerialUSB.print(dacv);
      SerialUSB.print(" stable ");
      SerialUSB.print(stable);
      SerialUSB.print(" locked ");
      SerialUSB.print(locked);
      SerialUSB.print(" GPSlock ");
      SerialUSB.print(gpslock);
      SerialUSB.print(" GPSdata ");
      SerialUSB.print(gpsdata);
      SerialUSB.print(" PPS ");
      SerialUSB.print(pps);
      SerialUSB.println("");
    } else if (incomingByte == 'S') { // Report more status
      SerialUSB.print("HOT ");
      SerialUSB.print(digitalRead(HOT_PIN));
      SerialUSB.print(" int-flag ");  // Interrupt flag
      SerialUSB.print(flag);
      //SerialUSB.print(" test pin ");
      //SerialUSB.print(digitalRead(4));
      SerialUSB.println("");
    } else if (incomingByte == 'G') { // Control GPS data debug
      gpsdebug = 0;
    } else if (incomingByte == 'g') {
      gpsdebug++;
    } else if (incomingByte == 'T') { // Control printing $GPRMC lines
      gprmc = 0;
    } else if (incomingByte == 't') {
      gprmc = 1;
    } else if (incomingByte == '8') { // Serial1 speed = 4800
      Serial1.begin(4800);
    } else if (incomingByte == '9') { // Serial1 speed = 9600
      Serial1.begin(9600);
    } else if (incomingByte == 'a') { 
      float value = analogRead(A1);
      float voltage = value * 3.3 / 4096.0;
      SerialUSB.print(value);
      SerialUSB.print(" ");
      SerialUSB.println(voltage); // Print the voltage.
    } else if (incomingByte == 'Q') { // Set specific DAC values
      analogWrite(A0, 1023);
    } else if (incomingByte == 'A') {
      analogWrite(A0, 512);
    } else if (incomingByte == 'Z') {
      analogWrite(A0, 0);
    } else if (incomingByte == 'W') {
      analogWrite(A0, 768);
    } else if (incomingByte == 'X') {
      analogWrite(A0, 256);
    } else if (incomingByte == 'R') {
      Pd += 10;
      ADJUST = 1;
    } else if (incomingByte == 'V') {
      Pd -= 10;
      ADJUST = 1;
    } else if (incomingByte == 'I') { // Control I operations
      Ienable = 1;
    } else if (incomingByte == 'i') {
      Ienable = 0;
    } else if (incomingByte == 'O') { // Turn off actions
      settle = 1000000;
    } else if (incomingByte == 'o') {
      settle = 1;
    } else if (incomingByte == 'R') { // Reset
      dacv=1;
      Pd = Id = stable = 0;
      ADJUST = 1;
    } else if (incomingByte == '0') { // Test of GPS data
      Serial1.println("Test 1");
      if (Serial1.available() > 0) {
        SerialUSB.println("1: serial available");
      }
    } else if (incomingByte == ' ') { // Hello?
      SerialUSB.println("-");
    }
  }
}

// Monitor the GPS serial data
// Set a valid data flag (counter actually) when there is data
// Look at GPS data to see if it has a valid lock
int monitor_gps_serial()
{
  // $GPGSA,A,3,,,,,,16,18,,22,24,,,3.6,2.1,2.2*3C
  //          ^ Fix: 1=No fix 2=2d, 3=3d
  // $GPRMC,022615.00,A,LLLL.94152,N,lllll.79113,W,0.082,,280816,,,A*63
  //   I use this for setting computer time
  if (Serial1.available() > 0) {
    char input[100], fix;
    int length, newlock;
    gpsdata = 5;  // time out in 5 seconds
    //input = Serial1.readStringUntil('\n');
    length = Serial1.readBytesUntil('\n',input, 99);
    input[length] = '\0';   // strip \n
    input[length-1] = '\0'; // strip \r
    if (gpsdebug > 2) {
      SerialUSB.print("> ");
      SerialUSB.println(input);
    }
    if (!strncmp("$GPGSA", input, 6)) {
      fix = input[9];
      newlock = fix - '0';
      if (newlock == 1) {
        newlock = 0;
      }
      if (newlock != gpslock) {
        gpslock = newlock;
        SerialUSB.print("$GPGSA = ");
        SerialUSB.println(gpslock);
      }
      if (gpsdebug) {
        SerialUSB.print('=');
        SerialUSB.print(input);
        SerialUSB.print(" ");
        SerialUSB.print(newlock);
        SerialUSB.println("");
      } else if (gprmc) {
        SerialUSB.print(input);
      }
    } else if (gprmc && !strncmp("$GPRMC", input, 6)) {
      // Pass GPRMC lines through. That way a computer on the USB port can
      // set it's clock from the GPS
      SerialUSB.print(input);
    }
  }
}

// Set GPS LED based on the GPS status
// Off = no data
// Red = no lock
// Green = lock
// This is called every second.
void gps_status()
{
  if (gpsdata) {
    gpsdata--;  // count down the data received timer
    if (gpsdata == 0)
      SerialUSB.println("Lost GPS data"); // Reports only when first lost
  }
  if (gpsdata == 0) {
    // Turn off LED
    digitalWrite(GPS_LED_A, LOW);
    digitalWrite(GPS_LED_B, LOW);
  } else if (gpslock) {
    // Turn LED Green
    digitalWrite(GPS_LED_A, HIGH);
    digitalWrite(GPS_LED_B, LOW);
  } else {
    // Turn LED Red
    digitalWrite(GPS_LED_A, LOW);
    digitalWrite(GPS_LED_B, HIGH);
  }
}

void lock_status()
{
  // blink lock LED when stable but not locked
  //digitalWrite(LOCK_LED, locked? LOW::HIGH);

  if (locked) {
    digitalWrite(LOCK_LED, LOW);
  } else {
    if (stable) {
      digitalWrite(LOCK_LED, hb? HIGH:LOW);
    } else {
      digitalWrite(LOCK_LED, HIGH);
    }
  }
}

void ready_status()
{
#ifdef USE_HOT
  int hot, on;

  hot = digitalRead(HOT_PIN);
  on = hot && ready;
  digitalWrite(READY_LED, on? LOW:HIGH);
#else
#ifdef ON_STABLE
  digitalWrite(READY_LED, stable? LOW:HIGH);  // ON when stable
#else
  digitalWrite(READY_LED, stable? HIGH:LOW);  // OFF when stable (RED LED)
#endif
#endif
}

void heartbeat()
{
  // Called once per second when the GPS 1PPS is running
  // Toggle heartbeat LED
  hb = !hb;
  digitalWrite(HEARTBEAT_LED, hb? HIGH:LOW);
  //if (debug > 1) {
  //  SerialUSB.print("Heartbeat ");
  //  SerialUSB.println(hb);
  //}
}

int count(uint32_t *delta)
{
  int skip = 0;

  // Request count, synchronize with counter
  //REG_TC4_READREQ = TC_READREQ_RREQ | TC_READREQ_ADDR(0x10) ; // COUNT offset 0x10
  //while (TC4->COUNT32.STATUS.bit.SYNCBUSY) ;
  volatile uint32_t count = REG_TC4_COUNT32_COUNT ;
  //while (TC4->COUNT32.STATUS.bit.SYNCBUSY) ;

  if (current_count > last_count) {
    *delta = current_count - last_count;
  } else {
    // Counter wrapped.  The count is always high, so throw it away.
    *delta = ((uint32_t)2^32 - last_count) + current_count;
    if (debug) {
      SerialUSB.print("Wrap ");
      SerialUSB.print(last_count);
      SerialUSB.print(" ");
      SerialUSB.print(((uint32_t)2^32-last_count));
      SerialUSB.print(" ");
      SerialUSB.print(current_count);
      SerialUSB.print(" = ");
      SerialUSB.print(*delta);
      SerialUSB.println(" ");
    }
    skip=1;
  }

  last_count = current_count;

  return skip;
}

int check_outliers(int error)
{
  int skip = 0;
  if (stable && (error < -10 || error > 10)) {  // Bad sample - throw away.
    outliers++;
    SerialUSB.print(" Outlier ");
    SerialUSB.print(outliers);
    SerialUSB.print(" ");
    skip = 1;
    if (outliers > 10) {
      outliers = 0;
      stable = 0;
      skip = 0;
      SerialUSB.print("Too many outliers ");
    }
  } else {
    outliers = 0;
  }

  return skip;
}

// P controller
int Pcontroller(int error)
{
  int skip = 0;

  // The initial hunt should stop when the error is zero. After that,
  // Use an error band to prevent moving on GPS jitter
  if (!skip && ((stable && (error < -1 || error > 1)) || (!stable && error != 0)))  {
    //if (!skip && (error < -2 || error > 2))  // << only error band
    padjust = error * PD_ADJUST;
    Pd += padjust;
    SerialUSB.print(" P Adjust ");
    SerialUSB.print(padjust);
    SerialUSB.print(" ");

    // Reset I controller values
    Ia = 0;
    Iea = 0;
    Id = 0;
    skip = 1; // skip I controller
    stable = 0;
    locked = 0;
  } 

  return skip;
}

  // I controller
int Icontroller(uint32_t delta)
{
  int report = 0;
  int32_t diff;

  // Keep a moving average of the error over several seconds.
  // By keeping the average of the error, a float can be used instead of a double.
  // 24 bits is needed to hold a value of 10,000,000 and the FP internals results in
  // no bits being available for the fraction. Thus, a double is required.
  //
  // I'm not observing a significant difference in averaging over 64 seconds vs 16 seconds
  // a off-by-1 jitter changes the error by 0.04 instead of 0.08.  I don't think this
  // allows tightening up the tolerance (+-10, below).
  diff = delta - 10000000;
  //Ia = ((Ia * 7.0)+diff) / 8.0;
  Iea = ((Iea * 15.0)+diff) / 16.0;
  //Iea = ((Iea * 63.0)+diff) / 64.0;

  //Ierror = round((Ia - 10000000) * 100);
  Ierror = round((Iea) * 100);
  if (Ierror < -10 || Ierror > 10) {
    // +-5 was too tight of a tolerance on a FOX 801 
    float adjustf;
    adjustf = Ierror * If_ADJUST / 100;
    iadjust = -(int)adjustf;
    if (iadjust == 0) {
      iadjust = (adjustf<0) ? 1 : -1;
    }

    SerialUSB.print(" I AdjustF ");
    SerialUSB.print(Ierror);
    SerialUSB.print(" ");
    SerialUSB.print(iadjust);
    if (Isettle)
      Isettle--;
    if (Ienable && Isettle==0) {
      // Isettle is a settling time between adjustments. This gives the
      // I averaging time for the adjustment to take affect.  This prevents
      // overshooting or, worse, oscillating.
      // Alternatively, resetting the error accumulator will also give it
      // time to take affect.
      Id += iadjust;
      //Ia = 10000000;  // reset error accumulator
      Isettle = 4;
      locked = 0;
    } else if (iadjust != 0) {
      SerialUSB.print("(skipped) ");
    }
    SerialUSB.println("");
  } else {
    Isettle = 0;
    locked = 1;   // I isn't making changes, so it's locked
  }
}

int check_stable(int stable, int32_t error)
{
  // Set stable flag when the error is zero.
  // Stable flag is cleared in the P controller
  if (!stable && !(error < -1 || error > 1)) {
    stable = 1;
  } 

  return stable;
}
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
void loop()
{
  uint32_t delta;
  int32_t error;
  int skip = 0, report = 0;

  padjust = 0;
  iadjust = 0;

  serial_status();
  monitor_gps_serial(); 

  // check 1pps interrupt flag
  if (!flag) {
    if (millis() > nexthb) {
      // 1PPS from GPS is not being received.
      // Run LED status
      if (!gpslock) {
        locked=0;
      }
      gps_status();
      lock_status();
      ready_status();
      heartbeat();
      nexthb = millis() + 2000;
      pps = 0;
    }
    return;
  }
  flag = 0; // Clear
  nexthb = millis() + 2000;
  pps = 1;

  if ((skip = count(&delta)) > 0) {
  }

  // Settle counter allows skipping a sample to allow the oscillator to settle,
  // e.g. on start-up or after making a large adjustment
  if (settle > 0) {
    skip = 1;
    settle--;
  }

  if (skip && debug) {
    SerialUSB.print("Skip ");
    report = 1;
  }

  // Don't operate if there isn't GPS lock.
  // Require a sample after getting lock before operating.
  // The NEO 7 GPS I have doesn't produce 1PPS when it doesn't have lock.
  // (this is located after the above skip check to avoid setting report=1)
  if (!gpslock) {
    skip = 1;
    settle=1;
    locked=0;
  }

  error = 10000000 - delta;

  if (!skip) {
    if ((skip = check_outliers(error)) > 0) {
      report = 1;
    }
  }

  if (!skip) {
    if ((skip = Pcontroller(error)) > 0) {
      report = 1;
    }
  }

  if (!skip) {
    stable = check_stable(stable, error);
  }

  if (!skip && stable) {
    Icontroller(delta);
  }

  info(padjust | iadjust | debug | report, delta, error);

  broken();

  adjust(padjust, iadjust, stable, skip);

  gps_status();
  lock_status();
  ready_status();
  heartbeat();
}
// vim: tabstop=8 expandtab shiftwidth=2 softtabstop=2
// vi: tabstop=8 expandtab shiftwidth=2 softtabstop=2

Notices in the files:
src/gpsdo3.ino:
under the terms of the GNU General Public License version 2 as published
